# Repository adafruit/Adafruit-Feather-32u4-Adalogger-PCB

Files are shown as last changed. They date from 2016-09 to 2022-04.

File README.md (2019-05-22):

## Adafruit Feather 32u4 Adalogger PCB
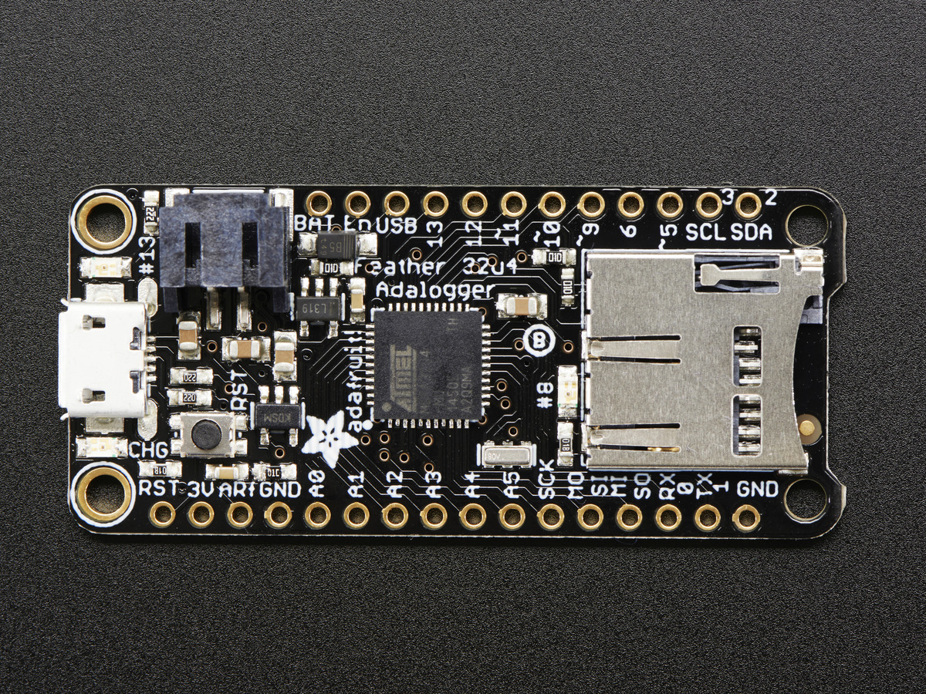
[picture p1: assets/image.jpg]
<a href="http://www.adafruit.com/products/2795"><br/>
Click here to purchase one from the Adafruit shop</a>

This is the Adafruit Feather 32u4 Adalogger - our take on an 'all-in-one' datalogger (or data-reader) with built in USB and battery charging. Its an Adafruit Feather 32u4 with a microSD holder ready to rock! We have other boards in the Feather family, check'em out here

At the Feather 32u4's heart is at ATmega32u4 clocked at 8 MHz and at 3.3V logic, a chip setup we've had tons of experience with as it's the same as the Flora. This chip has 32K of flash and 2K of RAM, with built in USB so not only does it have a USB-to-Serial program & debug capability built in with no need for an FTDI-like chip, it can also act like a mouse, keyboard, USB MIDI device, etc.

PCB files for the Adafruit Feather 32u4 Adalogger. The format is EagleCAD schematic and board layout
- https://www.adafruit.com/product/2795

### License

Adafruit invests time and resources providing this open source design, please support Adafruit and open-source hardware by purchasing products from [Adafruit](https://www.adafruit.com)!

All text above must be included in any redistribution

Designed by Limor Fried/Ladyada for Adafruit Industries.
Creative Commons Attribution/Share-Alike, all text above must be included in any redistribution. 
See license.txt for additional information.

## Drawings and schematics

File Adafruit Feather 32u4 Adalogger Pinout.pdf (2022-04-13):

# Adafruit Feather 32u4 Adalogger

# https://www.adafruit.com/products/2795

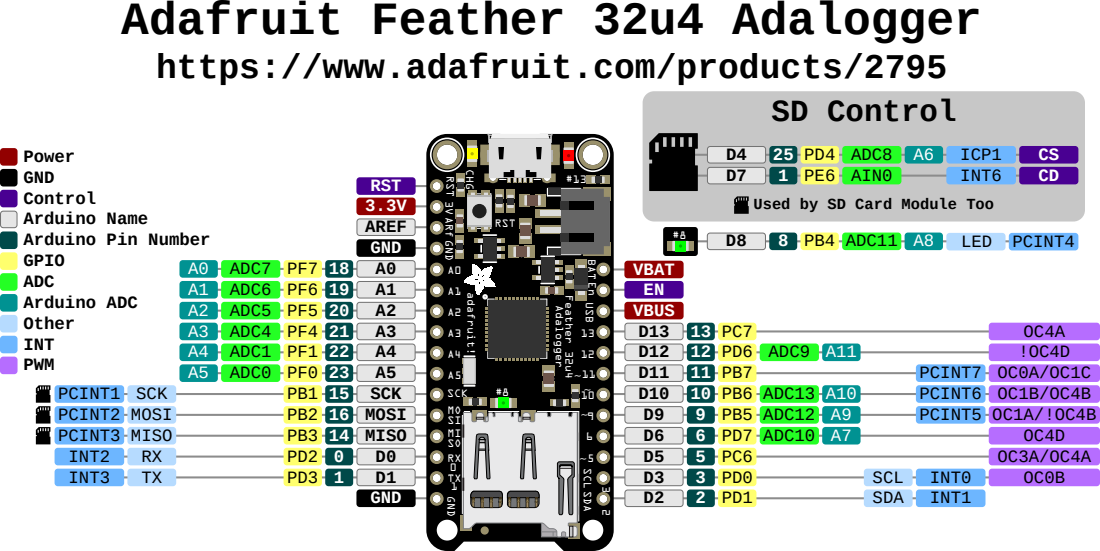
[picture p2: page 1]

Used by SD Card Module Too

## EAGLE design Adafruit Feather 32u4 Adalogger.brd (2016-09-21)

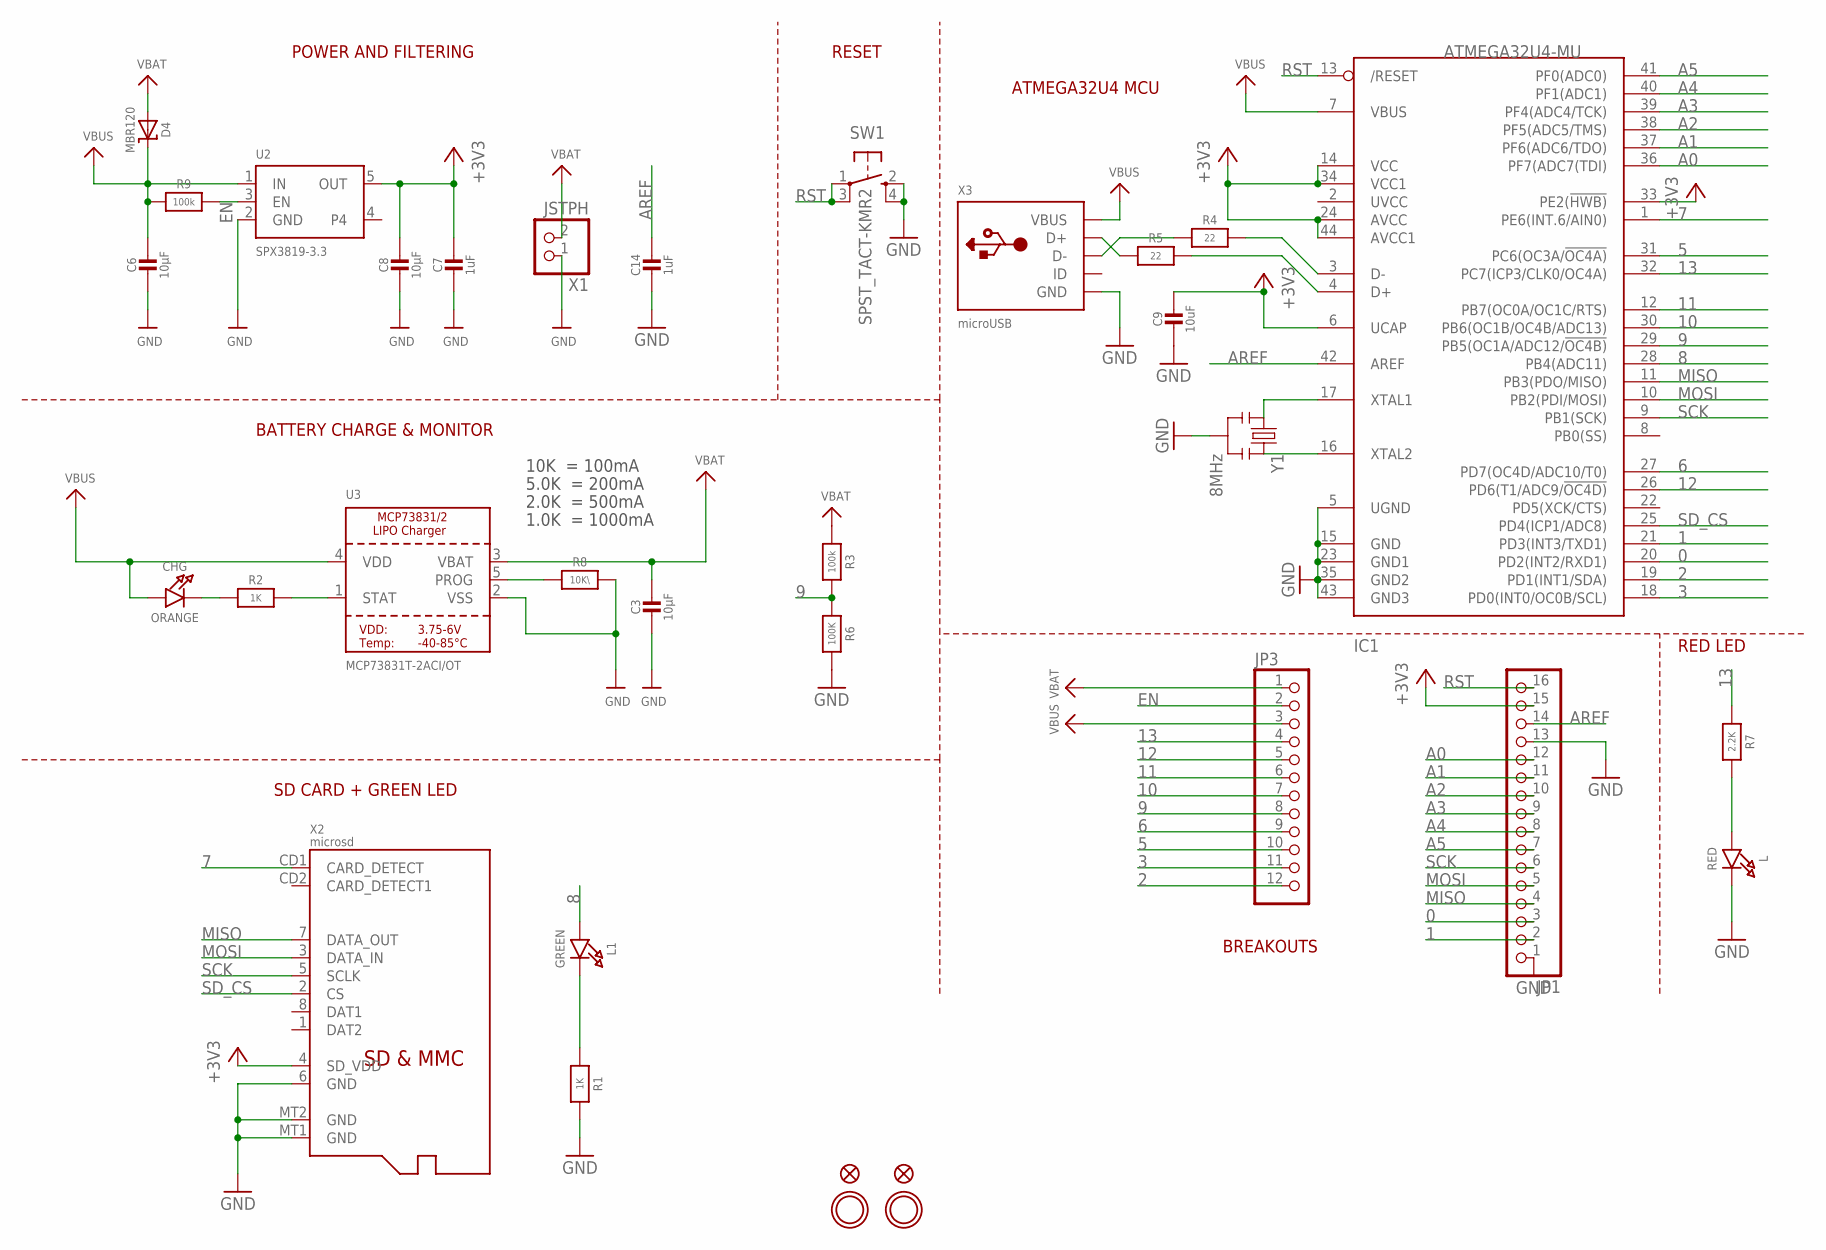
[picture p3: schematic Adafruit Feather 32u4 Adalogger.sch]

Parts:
C3, C6, C8: 10µF; 0805-NO
C7, C14: 1uF; 0603-NO
C9: 10uF; 0805-NO
CHG: ORANGE; CHIPLED_0805_NOOUTLINE
D4: MBR120; SOD-123
IC1: ATMEGA32U4-MU; TQFN44_7MM
JP1: HEADER-1X16ROUND; 1X16_ROUND
JP3: HEADER-1X12; 1X12_ROUND
L: RED; CHIPLED_0805_NOOUTLINE
L1: GREEN; CHIPLED_0805_NOOUTLINE
R1, R2: 1K; 0603-NO
R3, R9: 100k; 0603-NO
R4, R5: 22; 0603-NO
R6: 100K; _0603MP
R7: 2.2K; 0603-NO
R8: 10K\; 0603-NO
SW1: SPST_TACT-KMR2; KMR2
U2: SPX3819-3.3; SOT23-5
U3: MCP73831T-2ACI/OT; SOT23-5
U$31, U$32: MOUNTINGHOLE2.5; MOUNTINGHOLE_2.5_PLATED
U$34, U$35: FIDUCIAL""; FIDUCIAL_1MM
X1: JSTPH; JSTPH2
X2: microsd; MICROSD
X3: microUSB; 4UCONN_20329_V2
Y1: 8MHz; RESONATOR-SMD

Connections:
0: IC1.20 (PD2(INT2/RXD1)), JP1.3
1: IC1.21 (PD3(INT3/TXD1)), JP1.2
2: IC1.19 (PD1(INT1/SDA)), JP3.12
3: IC1.18 (PD0(INT0/OC0B/SCL)), JP3.11
5: IC1.31 (PC6(OC3A/!OC4A)), JP3.10
6: IC1.27 (PD7(OC4D/ADC10/T0)), JP3.9
7: IC1.1 (PE6(INT.6/AIN0)), X2.CD1 (CARD_DETECT)
8: IC1.28 (PB4(ADC11)), L1.A
9: IC1.29 (PB5(OC1A/ADC12/!OC4B)), JP3.8, R3.2, R6.1
10: IC1.30 (PB6(OC1B/OC4B/ADC13)), JP3.7
11: IC1.12 (PB7(OC0A/OC1C/RTS)), JP3.6
12: IC1.26 (PD6(T1/ADC9/!OC4D)), JP3.5
13: IC1.32 (PC7(ICP3/CLK0/OC4A)), JP3.4, R7.1
+3V3: C7.1, C8.1, C9.1, IC1.6 (UCAP), IC1.14 (VCC), IC1.24 (AVCC), IC1.33 (PE2(!HWB)), IC1.34 (VCC1), IC1.44 (AVCC1), JP1.15, U2.5 (OUT), X2.4 (SD_VDD)
A0: IC1.36 (PF7(ADC7(TDI)), JP1.12
A1: IC1.37 (PF6(ADC6/TDO)), JP1.11
A2: IC1.38 (PF5(ADC5/TMS)), JP1.10
A3: IC1.39 (PF4(ADC4/TCK)), JP1.9
A4: IC1.40 (PF1(ADC1)), JP1.8
A5: IC1.41 (PF0(ADC0)), JP1.7
AREF: C14.1, IC1.42 (AREF), JP1.14
D+: IC1.4 (D+), R5.2
D-: IC1.3 (D-), R4.2
EN: JP3.2, R9.2, U2.3 (EN)
GND: C3.2, C6.2, C7.2, C8.2, C9.2, C14.2, IC1.5 (UGND), IC1.15 (GND), IC1.23 (GND1), IC1.35 (GND2), IC1.43 (GND3), JP1.1, JP1.13, L.C, R1.2, R6.2, R8.2, SW1.2 (S), SW1.4 (S1), U2.2 (GND), U3.2 (VSS), X1.1, X2.6 (GND), X2.MT1 (GND), X2.MT2 (GND), X3.BASE@1 (GND), X3.BASE@2 (GND), X3.GND, X3.SPRT@1 (GND), X3.SPRT@2 (GND), X3.SPRT@3 (GND), X3.SPRT@4 (GND), Y1.2
MISO: IC1.11 (PB3(PDO/MISO)), JP1.4, X2.7 (DATA_OUT)
MOSI: IC1.10 (PB2(PDI/MOSI)), JP1.5, X2.3 (DATA_IN)
unnamed: CHG.C, R2.1
unnamed: L.A, R7.2
unnamed: R2.2, U3.1 (STAT)
unnamed: R8.1, U3.5 (PROG)
unnamed: L1.C, R1.1
unnamed: IC1.16 (XTAL2), Y1.3
unnamed: IC1.17 (XTAL1), Y1.1
unnamed: R5.1, X3.D+
unnamed: R4.1, X3.D-
RST: IC1.13 (/RESET), JP1.16, SW1.1, SW1.3 (P1)
SCK: IC1.9 (PB1(SCK)), JP1.6, X2.5 (SCLK)
SD_CS: IC1.25 (PD4(ICP1/ADC8)), X2.2 (CS)
VBAT: C3.1, D4.A, JP3.1, R3.1, U3.3 (VBAT), X1.2
VBUS: C6.1, CHG.A, D4.C, IC1.7 (VBUS), JP3.3, R9.1, U2.1 (IN), U3.4 (VDD), X3.VBUS

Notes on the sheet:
POWER AND FILTERING
RESET
ATMEGA32U4 MCU
10K = 100mA
5.0K = 200mA
2.0K = 500mA
1.0K = 1000mA
BATTERY CHARGE & MONITOR
RED LED
BREAKOUTS
SD CARD + GREEN LED

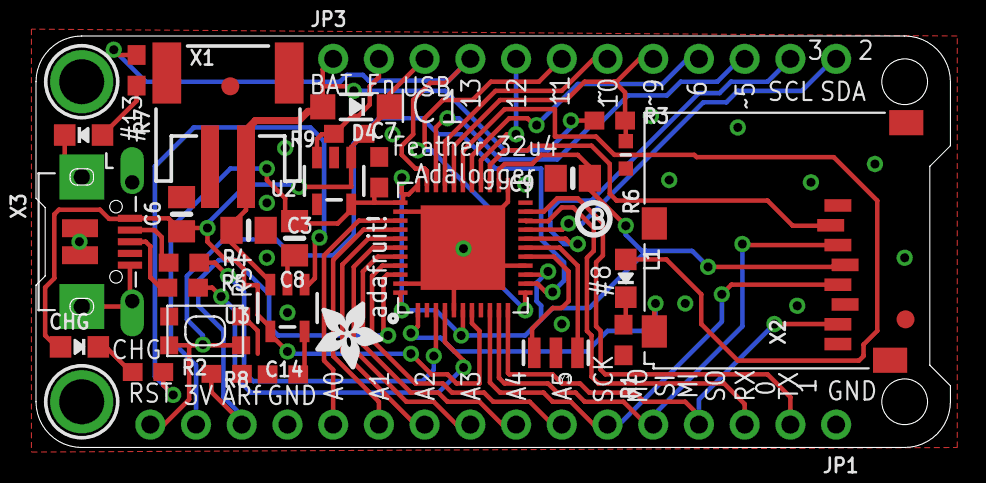
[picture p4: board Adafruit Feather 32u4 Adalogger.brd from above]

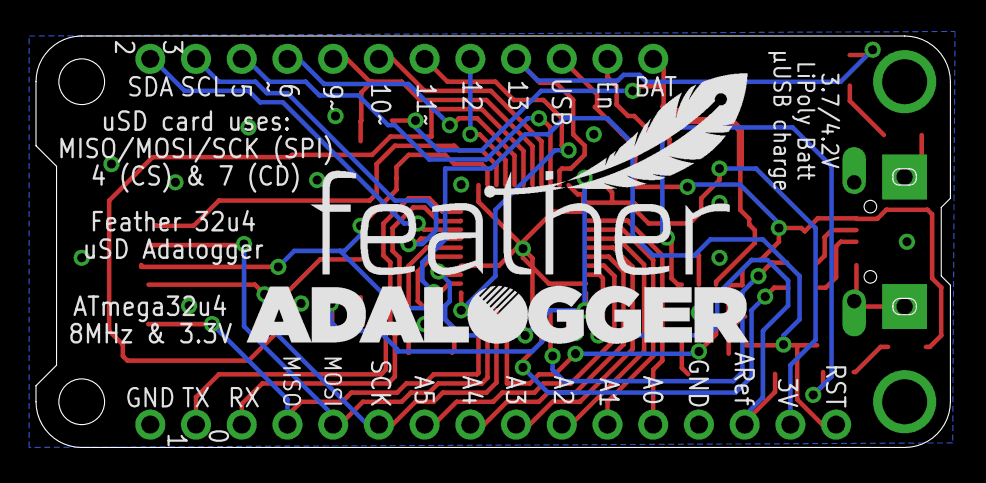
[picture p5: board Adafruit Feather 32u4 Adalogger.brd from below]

Board: 2 copper layers, 50.8 x 22.9 mm, 37 parts (2 on the bottom side), 41 nets.

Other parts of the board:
U$4: FEATHERLOGO
U$5: PCBFEAT-REV-040
U$6: ADALOGGER_LOGO
U$7: ADAFRUIT_3.5MM

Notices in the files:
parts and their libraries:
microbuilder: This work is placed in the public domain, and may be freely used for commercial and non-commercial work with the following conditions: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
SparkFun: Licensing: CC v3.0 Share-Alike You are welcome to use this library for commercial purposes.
